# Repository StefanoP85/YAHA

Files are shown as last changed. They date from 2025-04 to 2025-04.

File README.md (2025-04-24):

# YAHA
YAHA: Yet Another Headphone Amplifier

This is my first electronic project, a simple headphone amplifier, clearly inspired by the TubeAmp from Dario Murgia's repository @ [https://github.com/Darmur/tubeamp]. I designed it, to fit in the same enclosure too.

| Reference | Quantity | Description | Mouser part number | RS part number | AliExpress |
| --- | --- | --- | --- | --- | --- |
| R1, R102, R202|3|Resistore 4,7 KΩ 0,25 W|603-MFR-25FBF52-4K7|199-7625|
| R101, R201|2|Resistore 1 MΩ 0,125 W|603-MFR-12FTF52-1M|199-5032|
| R103, R203|2|Resistore 1 KΩ 0,25 W|603-MFR-25FBF52-1K|199-7601|
| R104, R204|2|Resistore 47 Ω 0,25 W|603-MFR-25FBF52-47R|199-7623|
| RV1|1|Potenziometro doppio audio 50 KΩ|688-RK09712200HA|249-9159|
| C1, C2|2|Condensatore elettrolitico 470 µF 16V|667-EEU-FC1C471B|249-1338|
| C3, C4|2|Condensatore ceramico multistrato 100nF 50V|594-K104K15X7RF5TH5|852-3277|
| C101, C201|2|Condensatore a film 2,2 µF 50V|80-R82CC4220Z370K |171-9233|
| C102, C202|2|Condensatore a film 1 nF 50V|594-K102K10X7RF53H5|240-4836|
| D1|1|LED rosso 3 mm|604-WP710A10SURC/E|619-4886|
| IC1|1|OPA2134PA|595-OPA2134PA|285-8069|
| IC2|1|TLE2426CLP|595-TLE2426CLPR||
| |1|Socket DIP-8|649-DILB8P223TLF|863-2734|
| |1|Connettore DC|710-694108301002|122-4883|https://www.aliexpress.com/item/33005175186.html
| |2|Jack audio 1/8" stereo 3P PJ-320A|||https://www.aliexpress.com/item/33029465106.html
| |1|Manopola per potenziometro|450-225||

Pictures of the components.
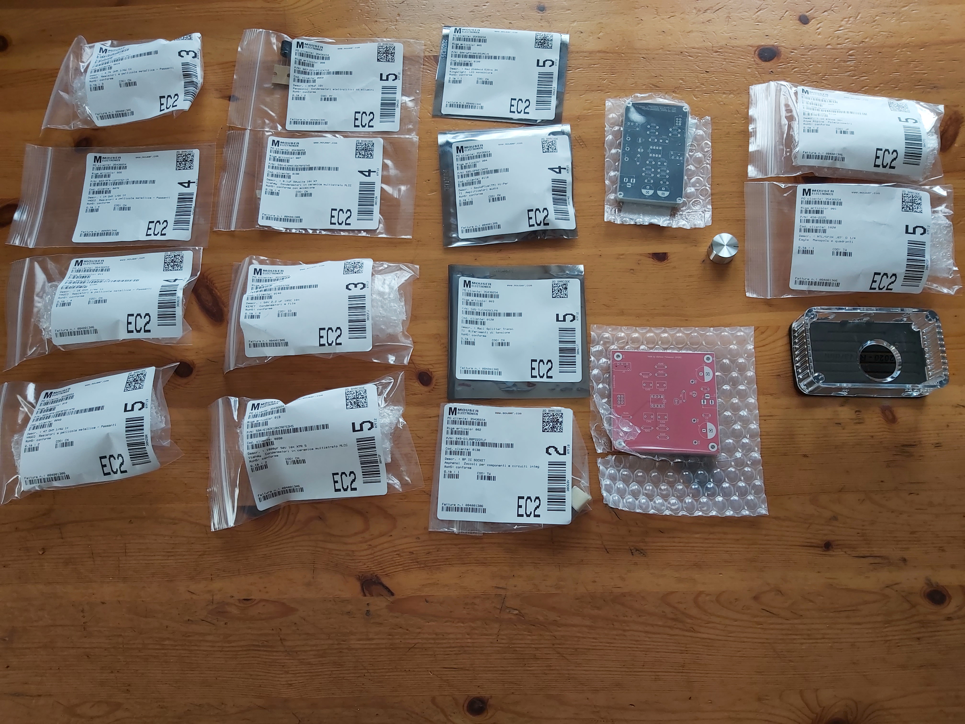
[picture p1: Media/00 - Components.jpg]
Components


PCB back: the red one is the prototype, the black one is the current version.
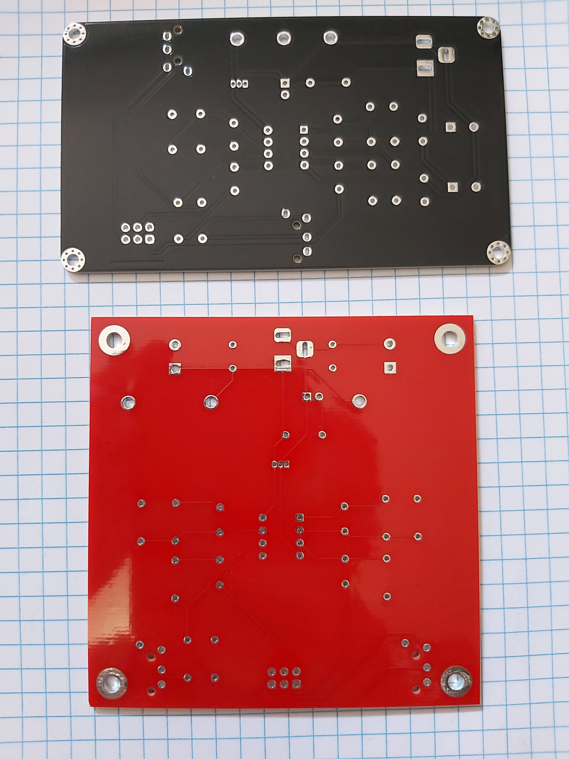
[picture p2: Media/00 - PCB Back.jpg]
PCB back


PCB front: the red one is the prototype, the black one is the current version.
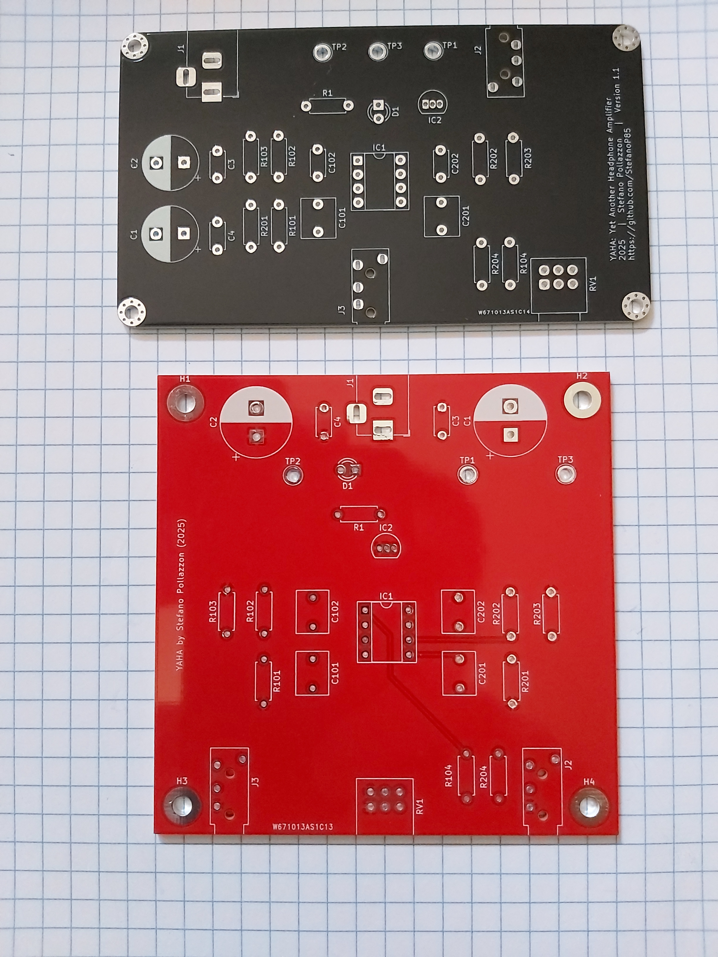
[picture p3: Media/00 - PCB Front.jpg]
PCB front


PCB assembled.
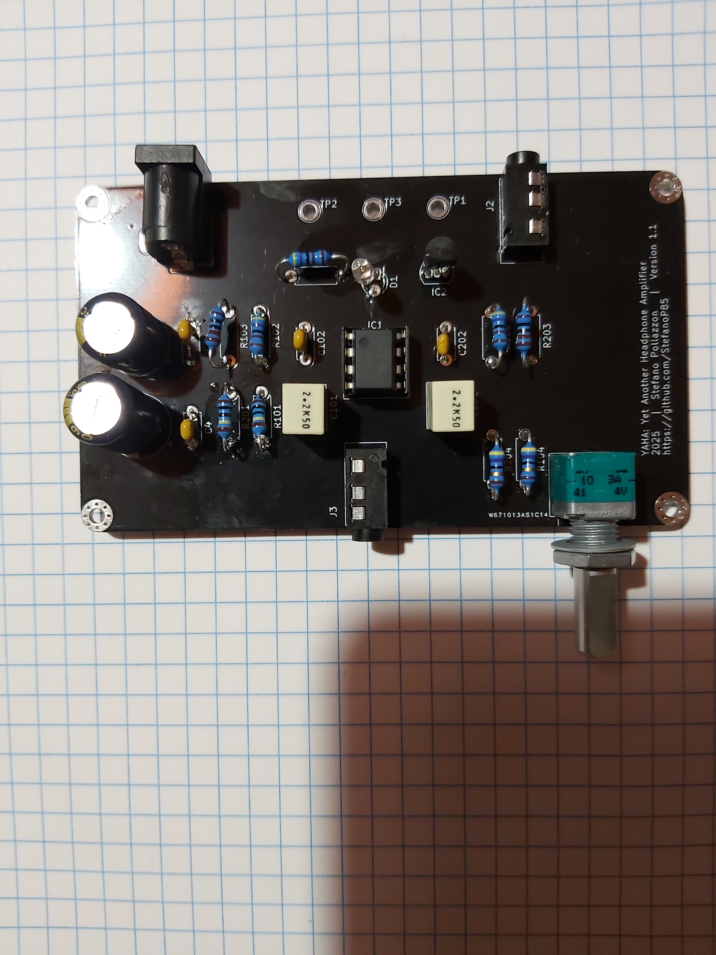
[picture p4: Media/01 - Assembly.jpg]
PCB assembled


Amplifier completed, with the 3D printed enclosure.
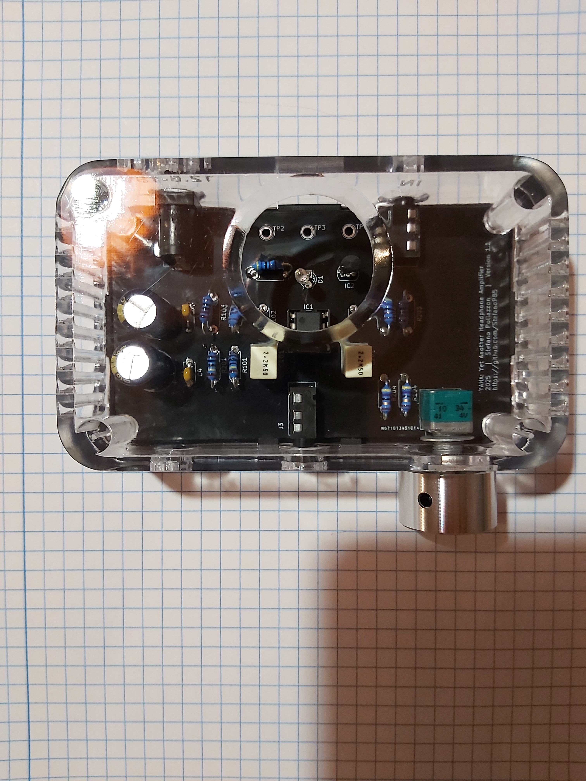
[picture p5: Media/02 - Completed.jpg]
Amplifier completed


The YAHA next to the TubeAmp from Dario Murgia.
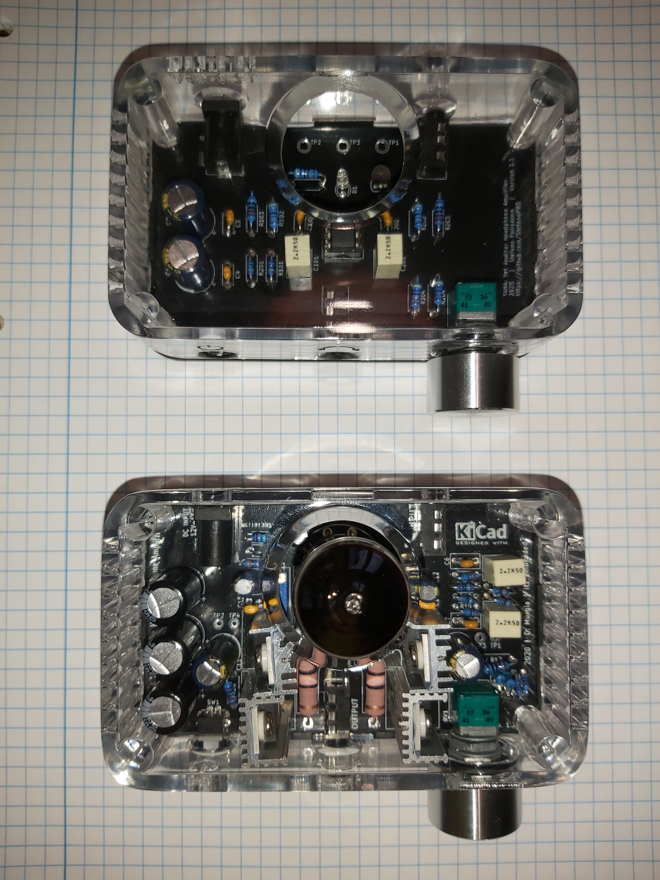
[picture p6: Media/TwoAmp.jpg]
Two amplifiers


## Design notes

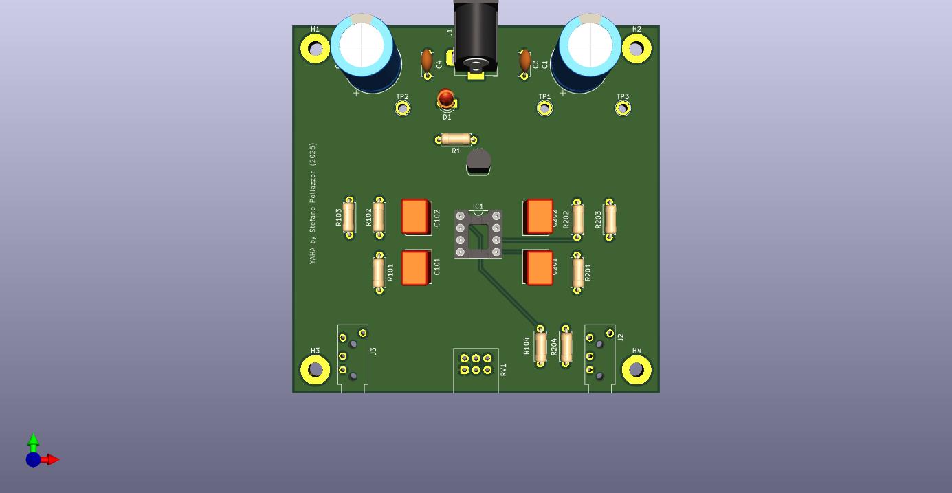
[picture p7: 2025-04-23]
Media/Version 1.0.jpg

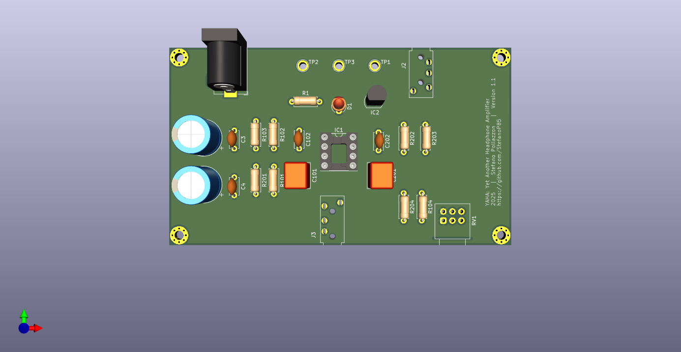
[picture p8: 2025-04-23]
Media/Version 1.1.png

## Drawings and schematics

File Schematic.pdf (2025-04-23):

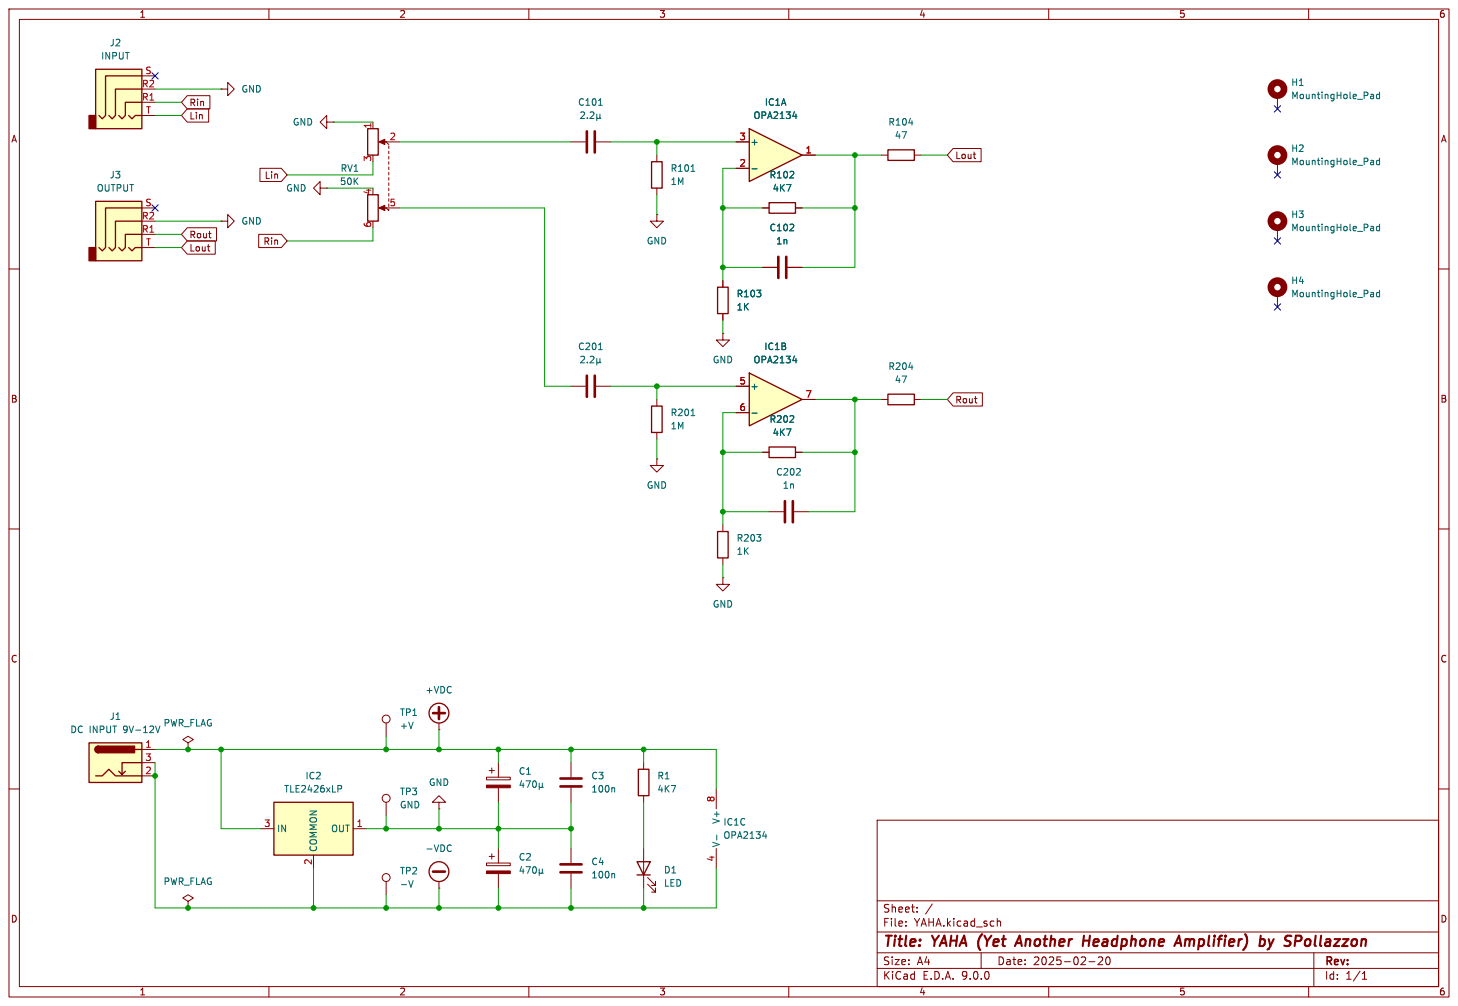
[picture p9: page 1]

File: YAHA.kicad_sch Sheet: /
Id: 1/1 Title: YAHA (Yet Another Headphone Amplifier) by SPollazzon

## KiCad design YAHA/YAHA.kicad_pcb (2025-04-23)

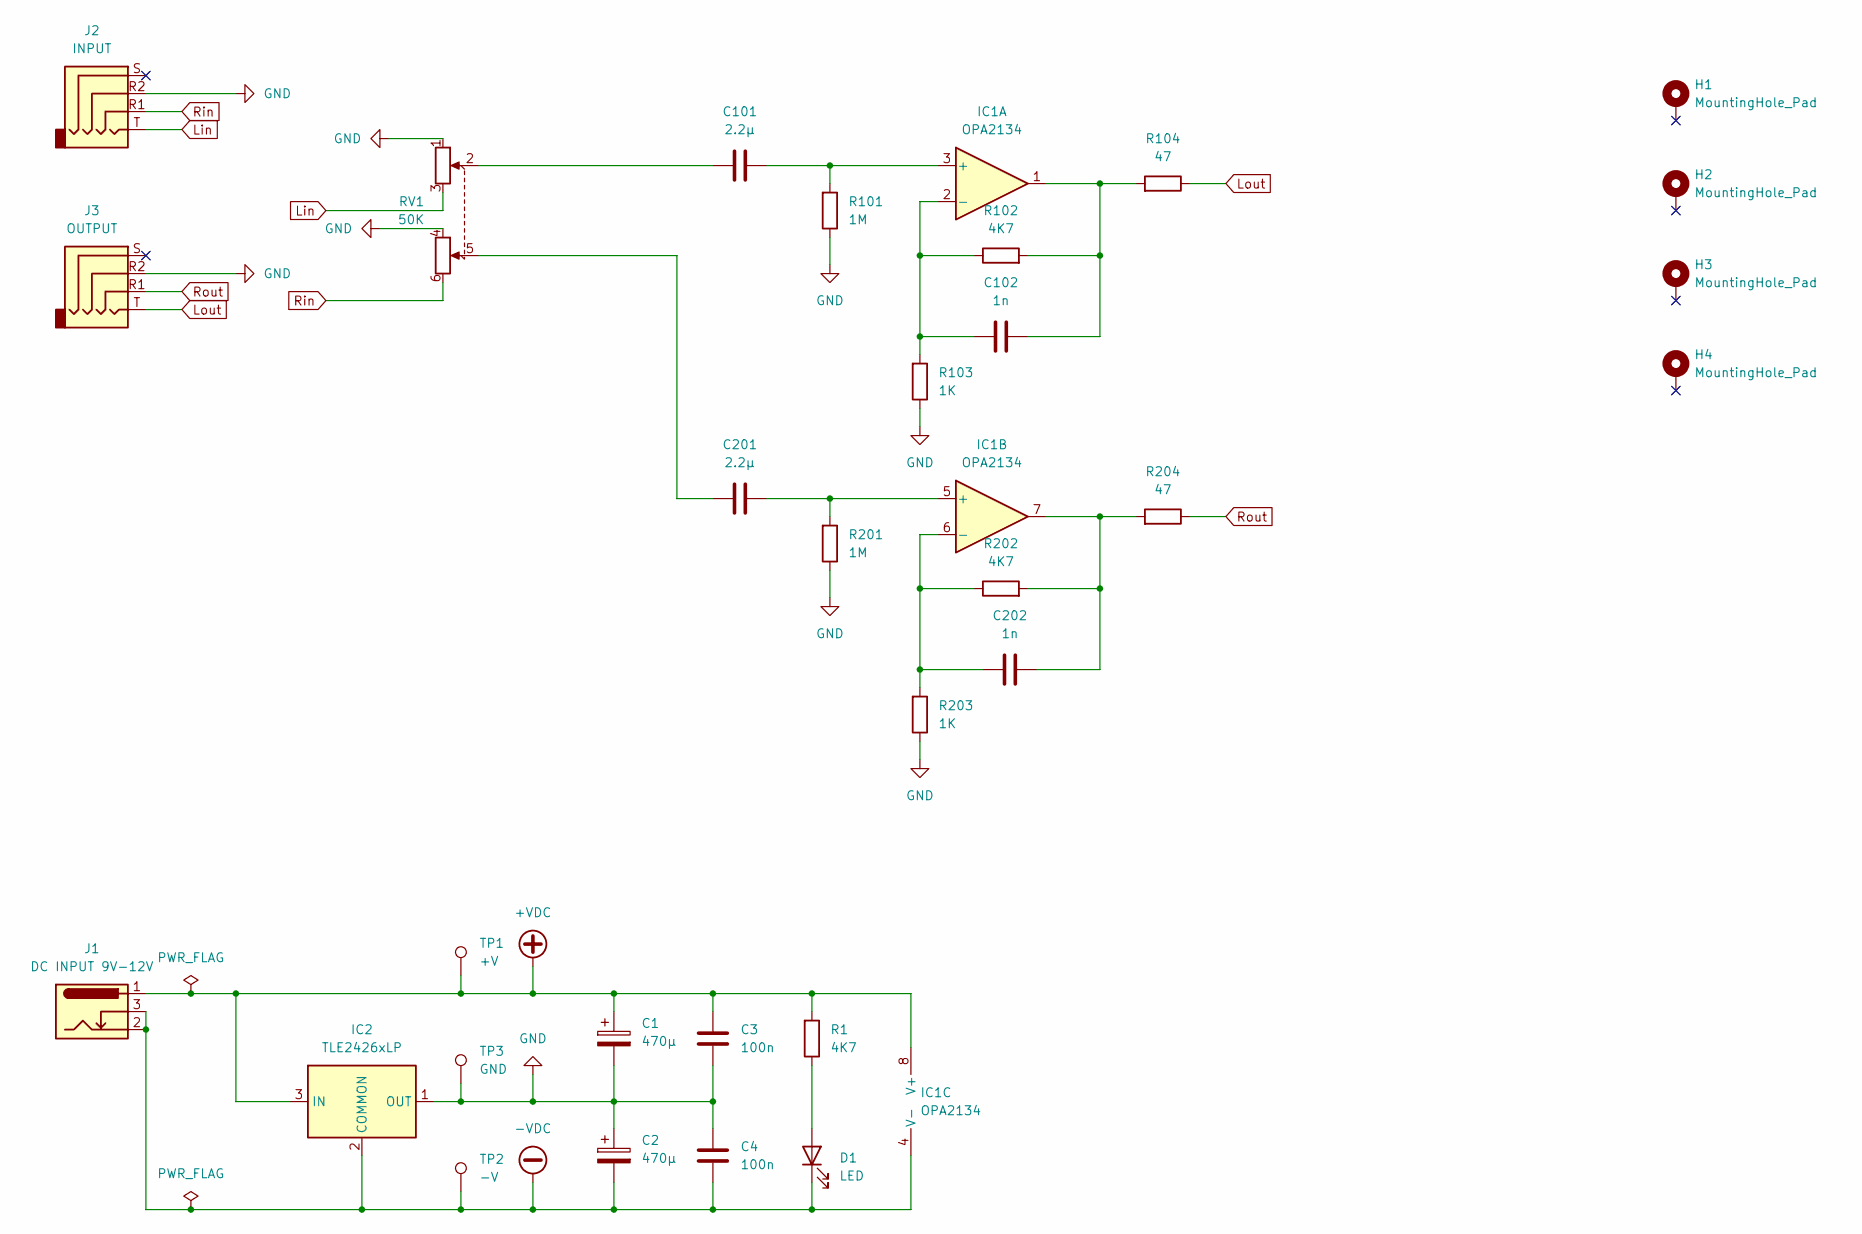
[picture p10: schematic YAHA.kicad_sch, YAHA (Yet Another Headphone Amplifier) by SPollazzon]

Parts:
C1, C2: 470µ; CP_Radial_D10.0mm_P5.00mm; Mouser part number 667-EEU-FC1C471B
C3, C4: 100n; C_Disc_D4.7mm_W2.5mm_P5.00mm; Mouser part number 594-K104K15X7RF5TH5
C101, C201: 2.2µ; C_Rect_L7.0mm_W6.0mm_P5.00mm; Mouser part number 80-R82CC4220Z370K
C102, C202: 1n; C_Disc_D4.7mm_W2.5mm_P5.00mm; Mouser part number 80-PFR5102J630J11L4
D1: LED; LED_D3.0mm; Mouser part number WP710A10SURC/E
H1, H2, H3, H4: MountingHole_Pad; MountingHole_2.5mm_Pad_Via
IC1: OPA2134; DIP-8_W7.62mm_Socket; Mouser part number 595-OPA2134PA, 649-DILB8P223TLF
IC2: TLE2426xLP; TO-92L_Inline_Wide; Mouser part number 595-TLE2426CLPR
J1: DC INPUT 9V-12V; BarrelJack_Horizontal
J2: INPUT; PJ-320A
J3: OUTPUT; PJ-320A
R1, R102, R202: 4K7; R_Axial_DIN0207_L6.3mm_D2.5mm_P7.62mm_Horizontal; Mouser part number 603-MFR-25FBF52-4K7
R101, R201: 1M; R_Axial_DIN0207_L6.3mm_D2.5mm_P7.62mm_Horizontal; Mouser part number 603-MFR-25FBF52-1M
R103, R203: 1K; R_Axial_DIN0207_L6.3mm_D2.5mm_P7.62mm_Horizontal; Mouser part number 603-MFR-25FBF52-1K
R104, R204: 47; R_Axial_DIN0207_L6.3mm_D2.5mm_P7.62mm_Horizontal; Mouser part number 603-MFR-25FBF52-47R
RV1: 50K; Potentiometer_Alps_RK097_Dual_Horizontal; Mouser part number 688-RK09712200HA
TP1: +V; TestPoint_Plated_Hole_D2.0mm
TP2: -V; TestPoint_Plated_Hole_D2.0mm
TP3: GND; TestPoint_Plated_Hole_D2.0mm

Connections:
+VDC: C1.1, C3.2, IC1.8 (V+), IC2.3 (IN), J1.1, R1.1, TP1.1
-VDC: C2.2, C4.1, D1.1 (K), IC1.4 (V-), IC2.2 (COMMON), J1.2, J1.3, TP2.1
GND: C1.2, C2.1, C3.1, C4.2, IC2.1 (OUT), J2.R2, J3.R2, R101.2, R103.2, R201.2, R203.2, RV1.1, RV1.4, TP3.1
Lin: J2.T, RV1.3
Lout: J3.T, R104.2
unnamed: C101.2, RV1.2
unnamed: C102.1, IC1.1, R102.1, R104.1
unnamed: C201.2, RV1.5
unnamed: C202.1, IC1.7, R202.1, R204.1
unnamed: D1.2 (A), R1.2
unnamed: C101.1, IC1.3 (+), R101.1
unnamed: C102.2, IC1.2 (-), R102.2, R103.1
unnamed: C201.1, IC1.5 (+), R201.1
unnamed: C202.2, IC1.6 (-), R202.2, R203.1
Rin: J2.R1, RV1.6
Rout: J3.R1, R204.2

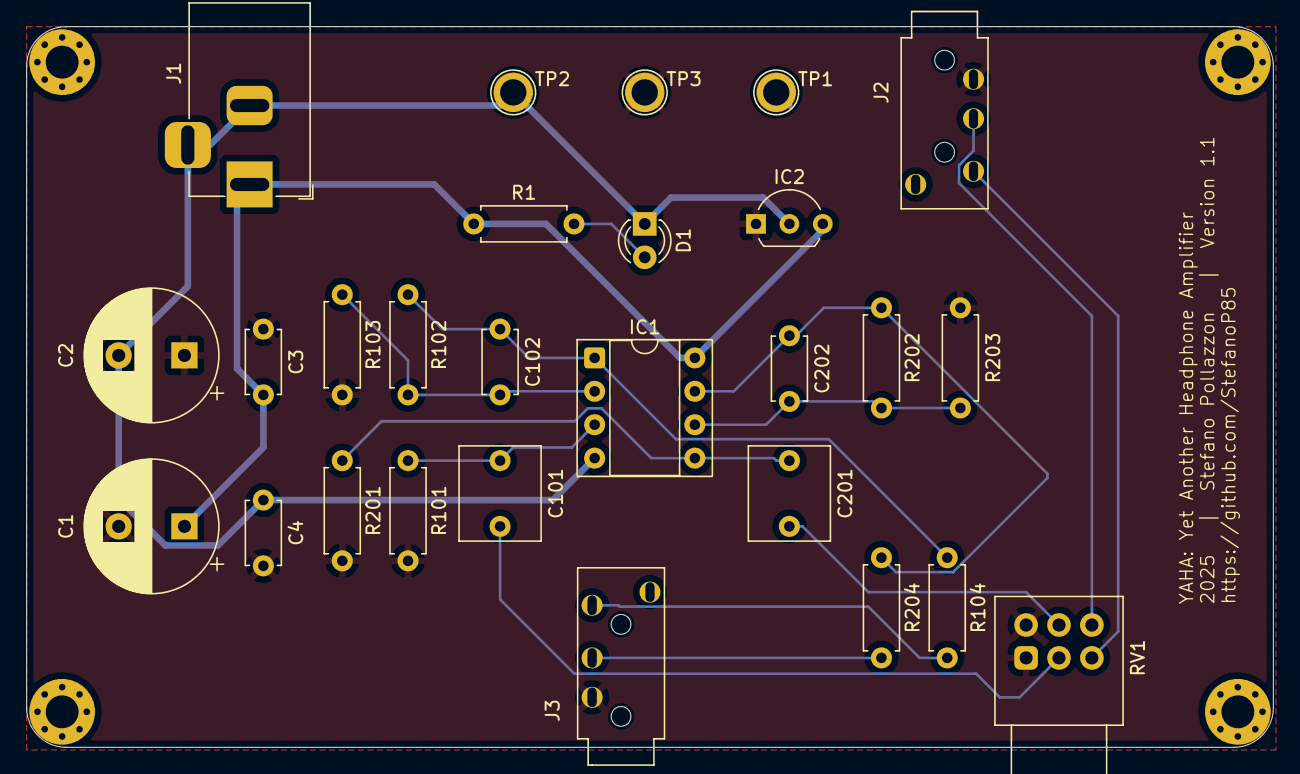
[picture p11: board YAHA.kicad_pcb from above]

Board: 2 copper layers, 94.8 x 54.8 mm, 31 parts (0 on the bottom side), 16 nets.

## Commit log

2025-04-23 Rename 00 - PCB Front.jpg to Media/00 - PCB Front.jpg
    Move pictures in the media folder
2025-04-23 Rename 01 - Assembly.jpg to Media/01 - Assembly.jpg
    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
2025-04-23 Rename 00 - PCB Back.jpg to Media/00 - PCB Back.jpg
    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
2025-04-23 Delete Media/00 - PCB Front.jpg
    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
2025-04-23 Delete Media/01 - Assembly.jpg
    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
